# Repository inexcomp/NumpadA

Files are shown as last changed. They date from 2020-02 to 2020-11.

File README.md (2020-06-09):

# NumpadA

A mechanical numpad.

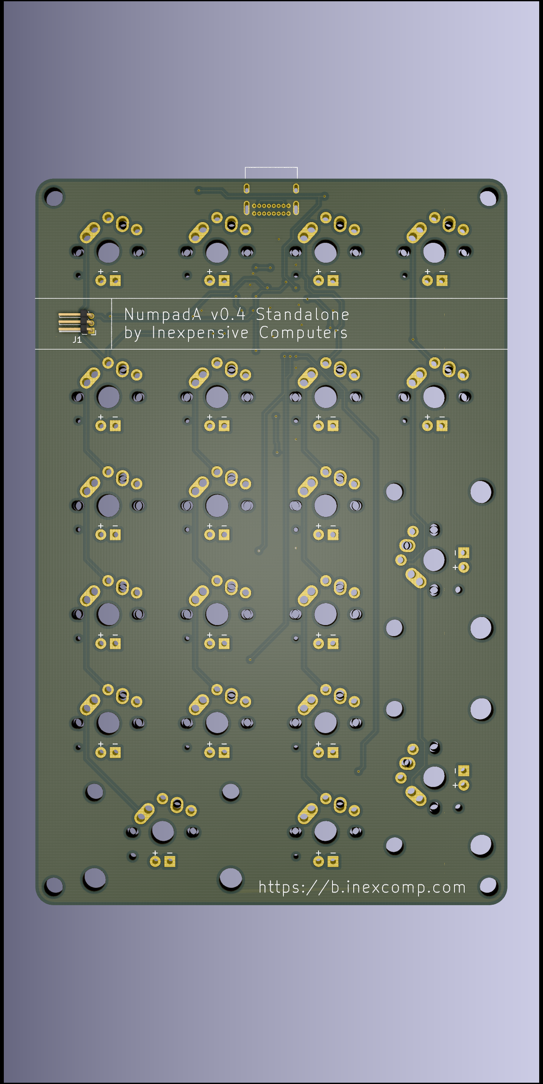
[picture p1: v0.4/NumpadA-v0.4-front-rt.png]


Branches:
- master: Pro Micro version with MX support only
- standalone: STM32F103-based standalone board with MX/Alps/Choc support

This repository contains the hardware and documentation. The software used with the hardware is QMK.

Software License: GPL v2

Hardware License: TAPR 1.0

Documentation License: CC BY-SA 4.0 International

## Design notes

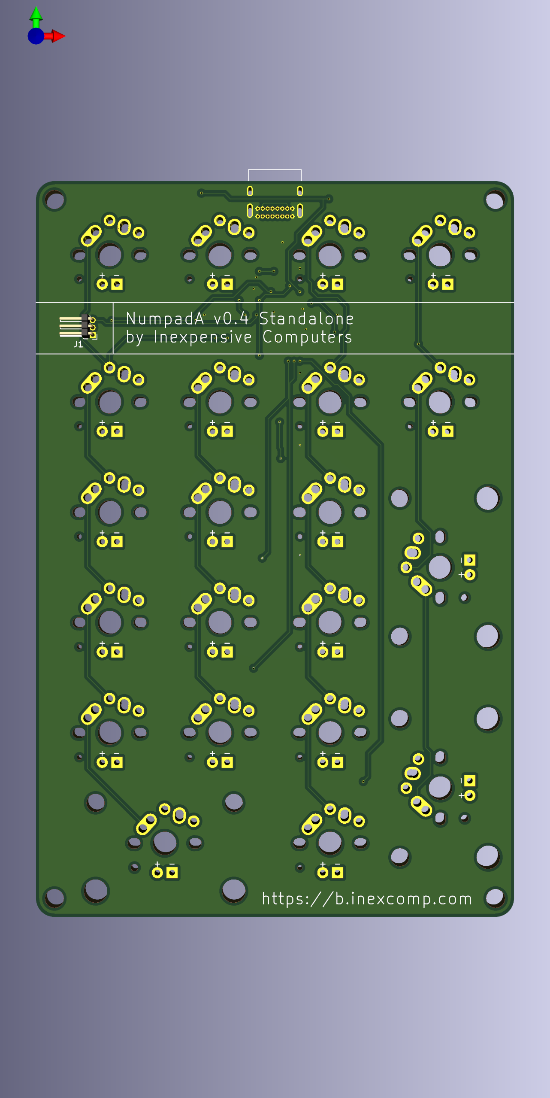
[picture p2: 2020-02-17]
v0.4/NumpadA-v0.4-front.png

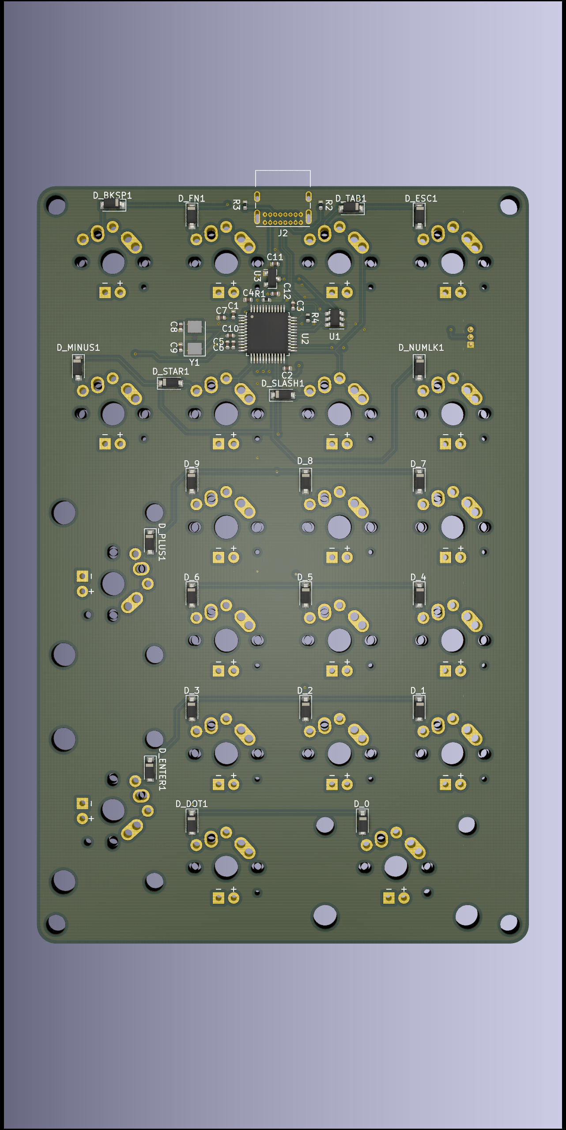
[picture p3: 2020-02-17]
v0.4/NumpadA-v0.4-back-rt.png

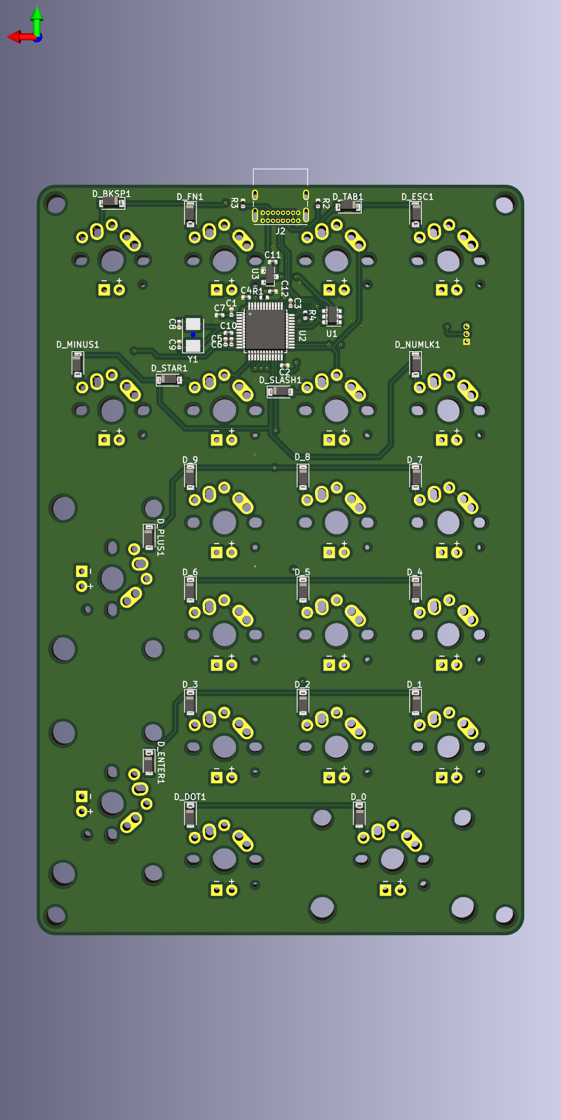
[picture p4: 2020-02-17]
v0.4/NumpadA-v0.4-back.png

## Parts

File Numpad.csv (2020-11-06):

Comment | Designator | Footprint | LCSC
1uf | C10,C1,C2 | Capacitor_SMD:C_0402_1005Metric | C52923
20pf | C3,C4 | Capacitor_SMD:C_0402_1005Metric | C1554
100nf | C6,C7,C8,C9,C12,C11,C5 | Capacitor_SMD:C_0402_1005Metric | C1525
BAT54C | D1,D2,D3,D4,D5,D6,D7,D8,D9,D10,D11 | Package_TO_SOT_SMD:SOT-23 | C375703
WS2813 | D12,D13,D14,D15,D16,D17 | LED_SMD:LED_WS2812_PLCC6_5.0x5.0mm_P1.6mm | C194323
SMD0805P050TF | F1 | Fuse:Fuse_0805_2012Metric_Castellated | C20978
TestPoint | GND1,SCK1,SIO1 | TestPoint:TestPoint_Pad_D2.0mm
USB_C_Receptacle_USB2.0 | J1 | Connector_USB:USB_C_Receptacle_HRO_TYPE-C-31-M-12
AO3401A | Q1 | Package_TO_SOT_SMD:SOT-23 | C15127
470R | R1,R5,R9,R13,R17,R21,R2,R6,R10,R14,R18,R3,R7,R11,R15,R19,R22,R4,R8,R12,R20 | Resistor_SMD:R_0805_2012Metric | C17710
10K | R23 | Resistor_SMD:R_0402_1005Metric | C25744
150R | R24 | Resistor_SMD:R_0402_1005Metric | C25082
1.5K | R25 | Resistor_SMD:R_0402_1005Metric | C25867
1M | R26 | Resistor_SMD:R_0402_1005Metric | C25082
10k | R28 | Resistor_SMD:R_0402_1005Metric | C25744
5.1K | R29,R27 | Resistor_SMD:R_0402_1005Metric | C25905
MX-LED | SW_ESC1,SW_FN1,SW_BKSP1,SW_NUMLK1,SW_SLASH1,SW_STAR1,SW_MINUS1,SW_1,SW_4,SW_5,SW_6,SW_7,SW_9,SW_DOT1,SW_TAB1,SW_8,SW_3,SW_2 | Keebio-Parts:MX-Alps-Choc-1U
MX-LED | SW_PLUS1,SW_ENTER1,SW_10 | Keebio-Parts:MX-Alps-Choc-2U-StabFlip
XC6206PxxxMR | U1 | Package_TO_SOT_SMD:SOT-23 | C5446
SRV05-4 | U2 | Package_TO_SOT_SMD:SOT-23-6 | C85364
STM32F103C8Tx | U3 | Package_QFP:LQFP-48_7x7mm_P0.5mm | C8734
8MHz | Y1 | Crystal:Crystal_SMD_5032-2Pin_5.0x3.2mm | C115962

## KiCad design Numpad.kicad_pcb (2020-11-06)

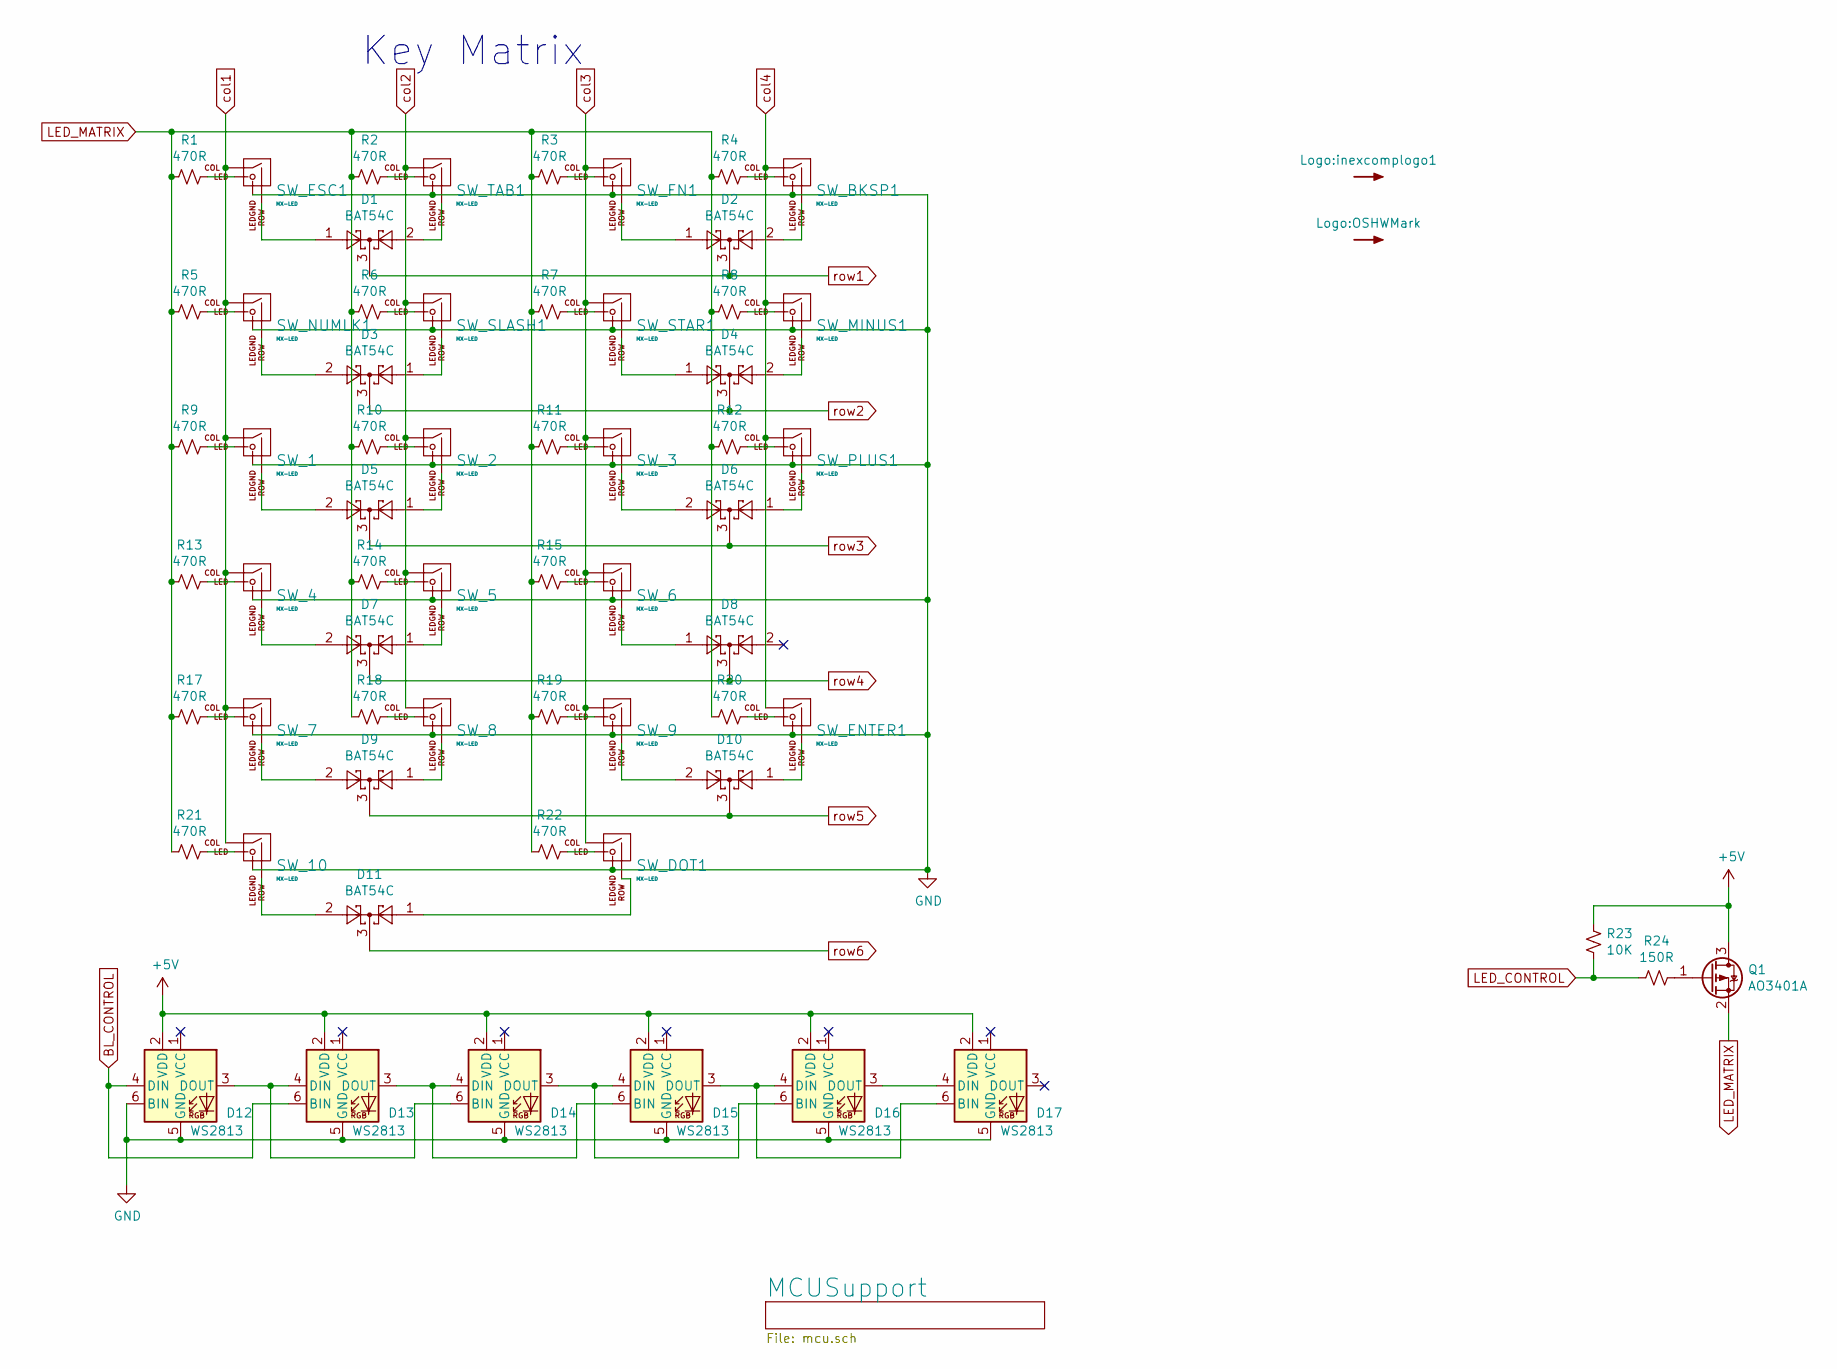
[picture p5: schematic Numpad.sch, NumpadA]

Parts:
D1, D2, D3, D4, D5, D6, D7, D8, D9, D10, D11: BAT54C; SOT-23; LCSC C375703
D12, D13, D14, D15, D16, D17: WS2813; LED_WS2812_PLCC6_5.0x5.0mm_P1.6mm; LCSC C194323
Q1: AO3401A; SOT-23; LCSC C15127
R1, R2, R3, R4, R5, R6, R7, R8, R9, R10, R11, R12, R13, R14, R15, R17, R18, R19, R20, R21, R22: 470R; R_0805_2012Metric; LCSC C17710
R23: 10K; R_0402_1005Metric; LCSC C25744
R24: 150R; R_0402_1005Metric; LCSC C25082
SW_1, SW_2, SW_3, SW_4, SW_5, SW_6, SW_7, SW_8, SW_9: MX-LED; MX-Alps-Choc-1U
SW_10: MX-LED; MX-Alps-Choc-2U-StabFlip
SW_BKSP1: MX-LED; MX-Alps-Choc-1U
SW_DOT1: MX-LED; MX-Alps-Choc-1U
SW_ENTER1: MX-LED; MX-Alps-Choc-2U-StabFlip
SW_ESC1: MX-LED; MX-Alps-Choc-1U
SW_FN1: MX-LED; MX-Alps-Choc-1U
SW_MINUS1: MX-LED; MX-Alps-Choc-1U
SW_NUMLK1: MX-LED; MX-Alps-Choc-1U
SW_PLUS1: MX-LED; MX-Alps-Choc-2U-StabFlip
SW_SLASH1: MX-LED; MX-Alps-Choc-1U
SW_STAR1: MX-LED; MX-Alps-Choc-1U
SW_TAB1: MX-LED; MX-Alps-Choc-1U

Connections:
+5V: D12.2 (VDD), D13.2 (VDD), D14.2 (VDD), D15.2 (VDD), D16.2 (VDD), D17.2 (VDD), Q1.3 (D), R23.1; also elsewhere on the board
BL_CONTROL: D12.4 (DIN), D13.6 (BIN); also elsewhere on the board
GND: D12.5 (GND), D12.6 (BIN), D13.5 (GND), D14.5 (GND), D15.5 (GND), D16.5 (GND), D17.5 (GND), SW_1.4 (LEDGND), SW_2.4 (LEDGND), SW_3.4 (LEDGND), SW_4.4 (LEDGND), SW_5.4 (LEDGND), SW_6.4 (LEDGND), SW_7.4 (LEDGND), SW_8.4 (LEDGND), SW_9.4 (LEDGND), SW_10.4 (LEDGND), SW_BKSP1.4 (LEDGND), SW_DOT1.4 (LEDGND), SW_ENTER1.4 (LEDGND), SW_ESC1.4 (LEDGND), SW_FN1.4 (LEDGND), SW_MINUS1.4 (LEDGND), SW_NUMLK1.4 (LEDGND), SW_PLUS1.4 (LEDGND), SW_SLASH1.4 (LEDGND), SW_STAR1.4 (LEDGND), SW_TAB1.4 (LEDGND); also elsewhere on the board
LED_CONTROL: R23.2, R24.2; also elsewhere on the board
LED_MATRIX: Q1.2 (S), R1.2, R2.2, R3.2, R4.2, R5.2, R6.2, R7.2, R8.2, R9.2, R10.2, R11.2, R12.2, R13.2, R14.2, R15.2, R17.2, R18.2, R19.2, R20.2, R21.2, R22.2
unnamed: D1.1, SW_ESC1.2 (ROW)
unnamed: D1.2, SW_TAB1.2 (ROW)
unnamed: D2.1, SW_FN1.2 (ROW)
unnamed: D2.2, SW_BKSP1.2 (ROW)
unnamed: D3.1, SW_SLASH1.2 (ROW)
unnamed: D3.2, SW_NUMLK1.2 (ROW)
unnamed: D4.1, SW_STAR1.2 (ROW)
unnamed: D4.2, SW_MINUS1.2 (ROW)
unnamed: D5.1, SW_2.2 (ROW)
unnamed: D5.2, SW_1.2 (ROW)
unnamed: D6.1, SW_PLUS1.2 (ROW)
unnamed: D6.2, SW_3.2 (ROW)
unnamed: D7.1, SW_5.2 (ROW)
unnamed: D7.2, SW_4.2 (ROW)
unnamed: D8.1, SW_6.2 (ROW)
unnamed: D9.1, SW_8.2 (ROW)
unnamed: D9.2, SW_7.2 (ROW)
unnamed: D10.1, SW_ENTER1.2 (ROW)
unnamed: D10.2, SW_9.2 (ROW)
unnamed: D11.1, SW_DOT1.2 (ROW)
unnamed: D11.2, SW_10.2 (ROW)
unnamed: D12.3 (DOUT), D13.4 (DIN), D14.6 (BIN)
unnamed: D13.3 (DOUT), D14.4 (DIN), D15.6 (BIN)
unnamed: D14.3 (DOUT), D15.4 (DIN), D16.6 (BIN)
unnamed: D15.3 (DOUT), D16.4 (DIN), D17.6 (BIN)
unnamed: D16.3 (DOUT), D17.4 (DIN)
unnamed: Q1.1 (G), R24.1
unnamed: R1.1, SW_ESC1.3 (LED)
unnamed: R2.1, SW_TAB1.3 (LED)
unnamed: R3.1, SW_FN1.3 (LED)
unnamed: R4.1, SW_BKSP1.3 (LED)
unnamed: R5.1, SW_NUMLK1.3 (LED)
unnamed: R6.1, SW_SLASH1.3 (LED)
unnamed: R7.1, SW_STAR1.3 (LED)
unnamed: R8.1, SW_MINUS1.3 (LED)
unnamed: R9.1, SW_1.3 (LED)
unnamed: R10.1, SW_2.3 (LED)
unnamed: R11.1, SW_3.3 (LED)
unnamed: R12.1, SW_PLUS1.3 (LED)
unnamed: R13.1, SW_4.3 (LED)
unnamed: R14.1, SW_5.3 (LED)
unnamed: R15.1, SW_6.3 (LED)
unnamed: R17.1, SW_7.3 (LED)
unnamed: R18.1, SW_8.3 (LED)
unnamed: R19.1, SW_9.3 (LED)
unnamed: R20.1, SW_ENTER1.3 (LED)
unnamed: R21.1, SW_10.3 (LED)
unnamed: R22.1, SW_DOT1.3 (LED)
col1: SW_1.1 (COL), SW_4.1 (COL), SW_7.1 (COL), SW_10.1 (COL), SW_ESC1.1 (COL), SW_NUMLK1.1 (COL); also elsewhere on the board
col2: SW_2.1 (COL), SW_5.1 (COL), SW_8.1 (COL), SW_SLASH1.1 (COL), SW_TAB1.1 (COL); also elsewhere on the board
col3: SW_3.1 (COL), SW_6.1 (COL), SW_9.1 (COL), SW_DOT1.1 (COL), SW_FN1.1 (COL), SW_STAR1.1 (COL); also elsewhere on the board
col4: SW_BKSP1.1 (COL), SW_ENTER1.1 (COL), SW_MINUS1.1 (COL), SW_PLUS1.1 (COL); also elsewhere on the board
row1: D1.3, D2.3; also elsewhere on the board
row2: D3.3, D4.3; also elsewhere on the board
row3: D5.3, D6.3; also elsewhere on the board
row4: D7.3, D8.3; also elsewhere on the board
row5: D9.3, D10.3; also elsewhere on the board
row6: D11.3; also elsewhere on the board

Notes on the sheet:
Key Matrix

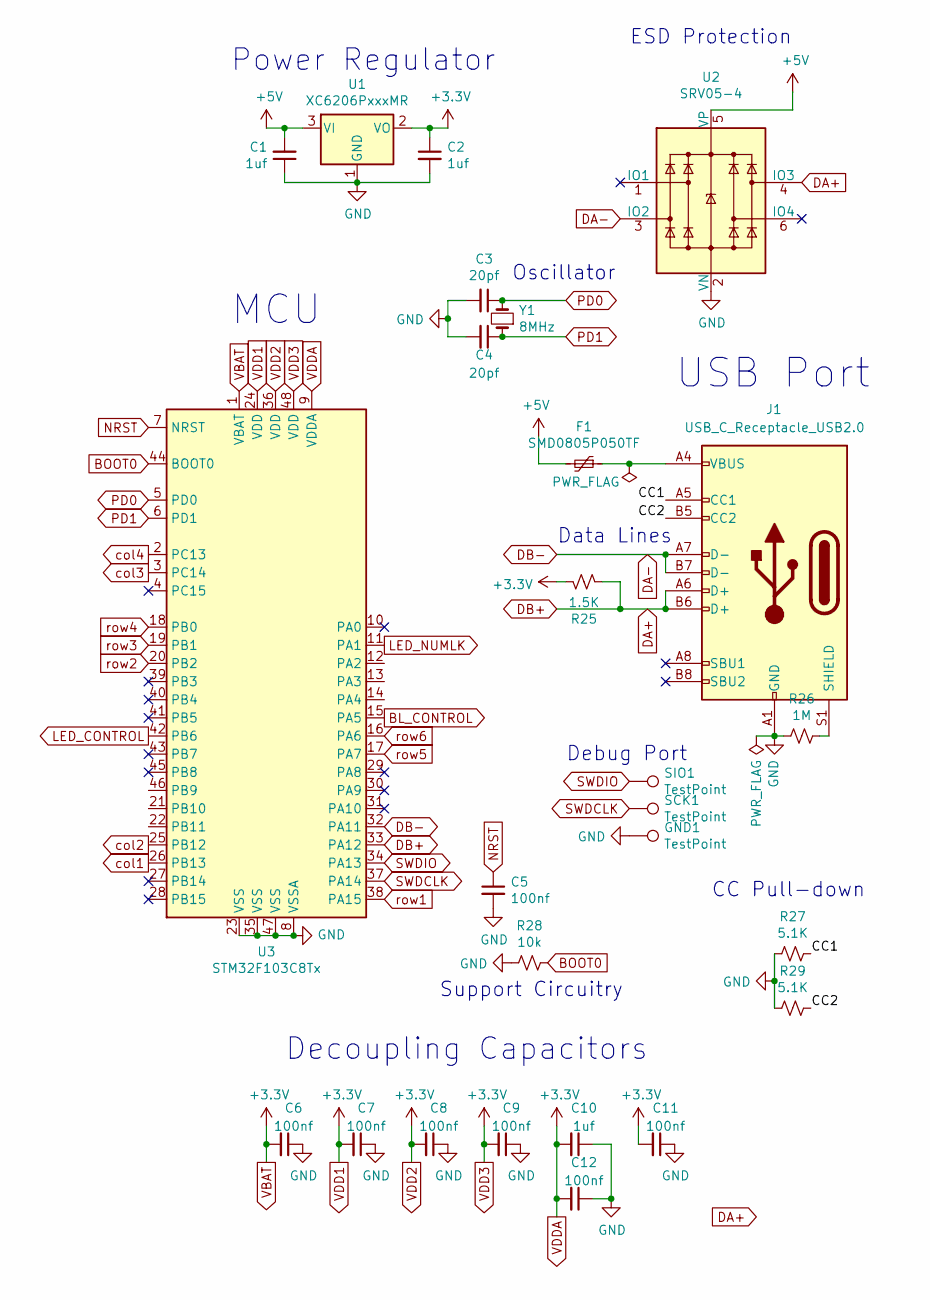
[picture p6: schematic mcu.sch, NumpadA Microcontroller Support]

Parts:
C1, C2, C10: 1uf; C_0402_1005Metric; LCSC C52923
C3, C4: 20pf; C_0402_1005Metric; LCSC C1554
C5, C6, C7, C8, C9, C11, C12: 100nf; C_0402_1005Metric; LCSC C1525
F1: SMD0805P050TF; Fuse_0805_2012Metric_Castellated; LCSC C20978
GND1: TestPoint; TestPoint_Pad_D2.0mm
J1: USB_C_Receptacle_USB2.0; USB_C_Receptacle_HRO_TYPE-C-31-M-12
R25: 1.5K; R_0402_1005Metric; LCSC C25867
R26: 1M; R_0402_1005Metric; LCSC C25082
R27, R29: 5.1K; R_0402_1005Metric; LCSC C25905
R28: 10k; R_0402_1005Metric; LCSC C25744
SCK1: TestPoint; TestPoint_Pad_D2.0mm
SIO1: TestPoint; TestPoint_Pad_D2.0mm
U1: XC6206PxxxMR; SOT-23; LCSC C5446
U2: SRV05-4; SOT-23-6; LCSC C85364
U3: STM32F103C8Tx; LQFP-48_7x7mm_P0.5mm; LCSC C8734
Y1: 8MHz; Crystal_SMD_5032-2Pin_5.0x3.2mm; LCSC C115962

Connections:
+5V: C1.2, F1.2, U1.3 (VI), U2.5 (VP); also elsewhere on the board
/MCUSupport/CC1: J1.A5 (CC1), R27.1
/MCUSupport/CC2: J1.B5 (CC2), R29.2
BL_CONTROL: U3.15 (PA5); also elsewhere on the board
BOOT0: R28.1, U3.44 (BOOT0)
DA+: J1.A6 (D+), J1.B6 (D+), R25.2, U2.4 (IO3), U3.33 (PA12)
DA-: J1.A7 (D-), J1.B7 (D-), U2.3 (IO2), U3.32 (PA11)
GND: C1.1, C2.2, C3.2, C4.2, C5.2, C6.1, C7.1, C8.1, C9.1, C10.1, C11.1, C12.1, GND1.1, J1.A1 (GND), J1.A12 (GND), J1.B1 (GND), J1.B12 (GND), R26.2, R27.2, R28.2, R29.1, U1.1 (GND), U2.2 (VN), U3.8 (VSSA), U3.23 (VSS), U3.35 (VSS), U3.47 (VSS); also elsewhere on the board
LED_CONTROL: U3.42 (PB6); also elsewhere on the board
LED_NUMLK: U3.11 (PA1)
NRST: C5.1, U3.7 (NRST)
unnamed: F1.1, J1.A4 (VBUS), J1.A9 (VBUS), J1.B4 (VBUS), J1.B9 (VBUS)
unnamed: J1.S1 (SHIELD), R26.1
PD0: C3.1, U3.5 (PD0), Y1.2
PD1: C4.1, U3.6 (PD1), Y1.1
SWDCLK: SCK1.1, U3.37 (PA14)
SWDIO: SIO1.1, U3.34 (PA13)
VBAT: C2.1, C6.2, C7.2, C8.2, C9.2, C10.2, C11.2, C12.2, R25.1, U1.2 (VO), U3.1 (VBAT), U3.9 (VDDA), U3.24 (VDD), U3.36 (VDD), U3.48 (VDD)
col1: U3.26 (PB13); also elsewhere on the board
col2: U3.25 (PB12); also elsewhere on the board
col3: U3.3 (PC14); also elsewhere on the board
col4: U3.2 (PC13); also elsewhere on the board
row1: U3.38 (PA15); also elsewhere on the board
row2: U3.20 (PB2); also elsewhere on the board
row3: U3.19 (PB1); also elsewhere on the board
row4: U3.18 (PB0); also elsewhere on the board
row5: U3.17 (PA7); also elsewhere on the board
row6: U3.16 (PA6); also elsewhere on the board

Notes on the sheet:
Decoupling Capacitors
ESD Protection
MCU
Data Lines
USB Port
Power Regulator
Debug Port
CC Pull-down
Oscillator
Support Circuitry

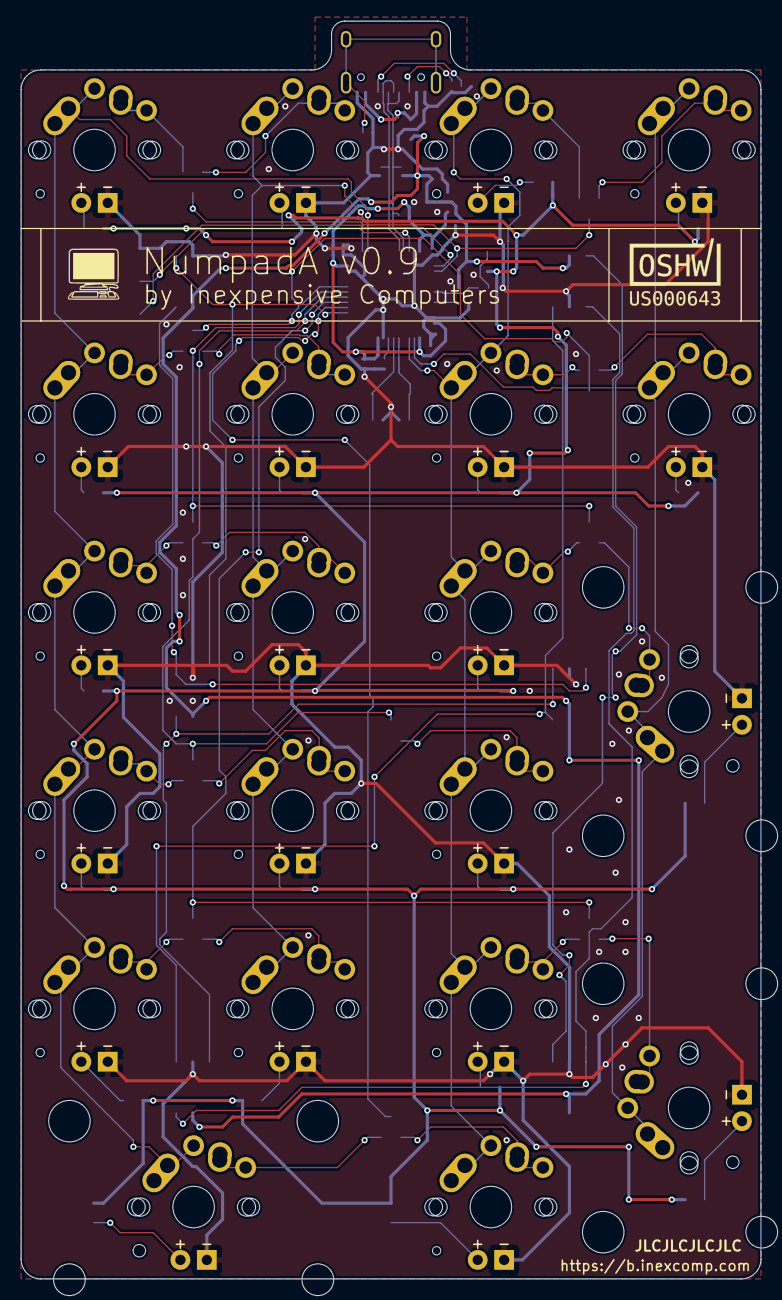
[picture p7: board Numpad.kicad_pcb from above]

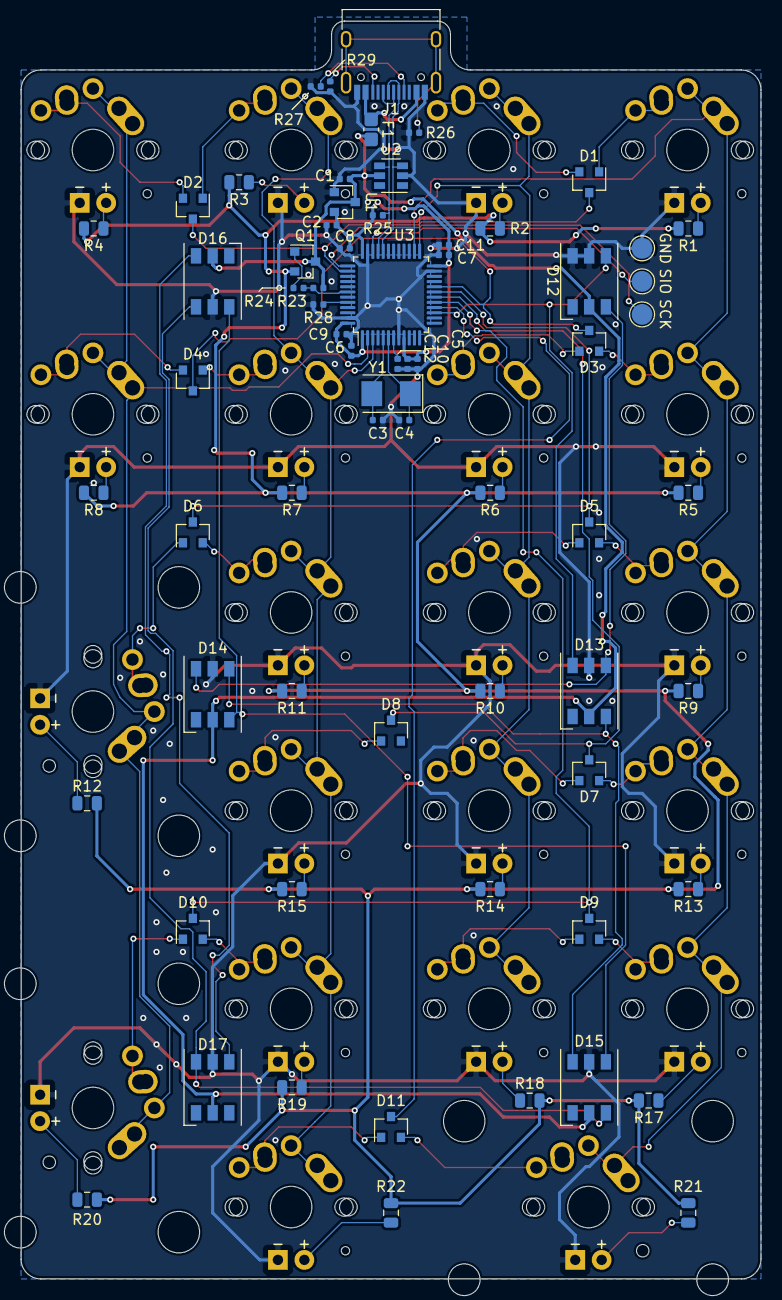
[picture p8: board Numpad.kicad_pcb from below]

Board: 2 copper layers, 71.1 x 120.9 mm, 88 parts (67 on the bottom side), 76 nets.

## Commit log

2020-01-19 changed schematic to use labels
    [Numpad.kicad_pcb, Numpad.sch]
2020-01-19 Fixed label orientation
    [Numpad.sch]
2020-01-19 Switched to standalone STM32F103
    [Numpad.kicad_pcb, Numpad.sch]
2020-01-19 Assigned SMD components and generated netlist
    [Numpad.sch]
2020-01-26 ground plane
    [Numpad.kicad_pcb, Numpad.sch]
2020-01-26 D+ pullup and some other things
    [Numpad.kicad_pcb, Numpad.sch]
2020-01-28 finalized v0.2
    [Numpad-B_Cu.gbr, Numpad-B_Mask.gbr, Numpad-B_Paste.gbr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]
2020-01-30 v0.3 minor tweaks
    [Numpad.kicad_pcb]
2020-01-30 0.3: removed dependencies on external libraries
    [Numpad.kicad_pcb, Numpad.sch]
2020-02-17 Tuned USB differential pair skew
    [Numpad.kicad_pcb]
2020-02-19 Widened power traces, fixed some routing
    [Numpad.kicad_pcb, Numpad.sch]
2020-02-19 Annotated and reformatted schematic
    [Numpad.kicad_pcb, Numpad.sch]
2020-02-19 Cleaned up repo
    [Numpad.dsn]
2020-02-20 Updated position of ESD protection diodes
    [Numpad.kicad_pcb, Numpad.sch]
2020-02-20 fixed some routing
    [Numpad.kicad_pcb]
2020-03-14 Changed LEDs to SOD323
    [Numpad.kicad_pcb, Numpad.sch]
2020-03-14 Fixed positioning of silkscreen labels
    [Numpad.kicad_pcb, Numpad.sch]
2020-03-14 Updated PCB sheet details
    [Numpad.kicad_pcb]
2020-03-14 Added place for JLCPCB order number
    [Numpad.kicad_pcb]
2020-03-23 Fixed header footprint
    [Numpad.kicad_pcb, Numpad.sch]
2020-06-05 some changes; added license
    [Numpad.kicad_pcb, Numpad.sch, mcu.sch]
